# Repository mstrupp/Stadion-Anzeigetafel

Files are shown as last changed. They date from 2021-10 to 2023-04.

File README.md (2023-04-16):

# Stadion-Anzeigetafel

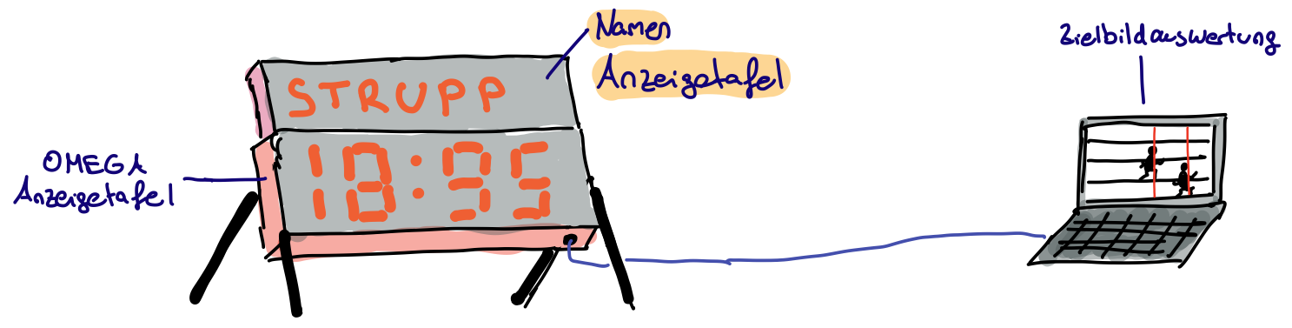
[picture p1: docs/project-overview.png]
Skizze des Projekts


## Zusammenfassung

Bei Leichtathletik Wettkämpfen erfolgt die Zeitmessung mit einer elektronischen Zeitmessanlage.
Der Startschuss startet die Stoppuhr und ein Zielbildauswerter bestimmt auf den Zielbildern die Zeiten der Läufer.

Während den Rennen wird auf einer Anzeigetafel die verstrichene Zeit dargestellt.
Außerdem können darauf nach einem Rennen die Zeiten der Läufer angezeigt werden.

In diesem Projekt wird eine Anzeigetafel entwickelt, die mit Zeitmesssystemen der Marke OMEGA kompatibel ist.
Die Anzeige kann eigenständig oder unterstützend eingesetzt werden.
Im eigenständigen Aufbau übernimmt sie alle Aufgaben der Anzeigetafel.
Im unterstützenden Modus werden Zusatzinformationen, wie der Name des Läufers, angezeigt, während eine weitere Anzeigetafel die Zeiten einblendet.

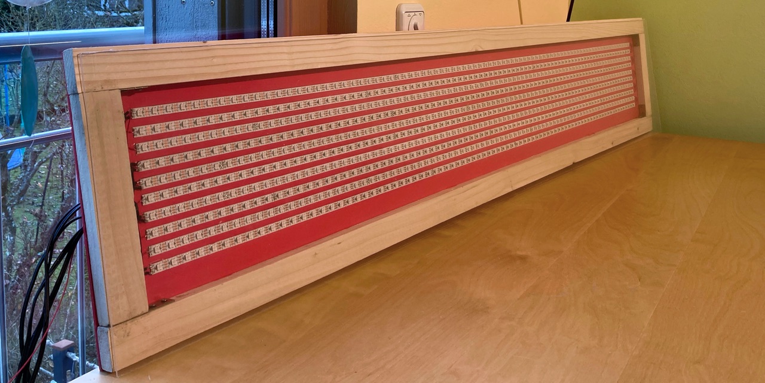
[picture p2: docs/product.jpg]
Fertiggestellte Anzeigetafel


## Technische Daten

Die Namen-Anzeigetafel ist ein LED-Display, das bis zu 12 Buchstaben in einer Zeile anzeigen kann.
Es ist aus einer Distanz von bis zu 75 m lesbar.
Der Benutzer kann zwischen verschiedenen Modi wählen, um den Namen, die Bahn oder die Platzierung anzuzeigen.
Die Helligkeit der Anzeige wird automatisch an die aktuellen Lichtverhältnisse angepasst.
Das regensichere Gehäuse schützt die Elektronik auch bei schlechtem Wetter mit der Schutzklasse IP24.

## Aufbau

### LED Anzeige

Das Display besteht aus einer LED-Matrix.
Dafür werden individuell adressierbare LED-Streifen verwendet. Die LED-Streifen haben eine Dichte von 60 LEDs pro Meter.
Der Pixel-Abstand beträgt etwa 1,7 cm.
Die Anzeige hat eine Auflösung von 83 x 10 Pixeln.
Die Maße der Anzeige betragen etwa 140 x 17 cm.
Jeder Buchstabe ist damit 6 x 10 Pixel bzw. 10 cm x 17 cm groß.

### Mikrocontroller

Die Ergebnis-Daten werden von einem STM Mikrocontroller auf einem Nucleo-32 Board empfangen und aufbereitet.
Die Daten werden von der Zielbildauswertung über die serielle RS422 Schnittstelle bereitgestellt.
Der Mikrocontroller berechnet unter den gegeben Benutzer-Einstellungen die Steuerungssignale für das Display.

### Schnittstellen

Für den Daten-Empfang wird der Data-Out Anschluss der OMEGA-Anzeigetafel verwendet.
Die Verbindung erfolgt über ein Datenkabel mit einem siebenpoligem Tuchel-Anschluss.
Zum Programmieren des Mikrocontrollers ist außerdem ein USB Anschluss am Gehäuse angebracht.

### Automatische Helligkeitsregulierung

Die Helligkeit der Anzeige wird automatisch an die aktuellen Lichtverhältnisse angepasst.
Zur Ermittlung der Umgebungshelligkeit wird ein Fotowiderstand eingesetzt.
Bei starker Sonneneinstrahlung wird zur verbesserten Lesbarkeit die Helligkeit des Displays erhöht.
Bei Dunkelheit wird die Helligkeit verringert.

### Betriebsmodi

Die Anzeigetafel verfügt über verschiedene Betriebsarten.
Es kann entweder der Name oder die Startnummer und die Bahn angezeigt werden.
Über Schalter kann der Bediener auswählen, was angezeigt wird. Ein weiterer Schalter aktiviert das Scrollen von langen Namen, die nicht mit zehn Zeichen dargestellt werden können.
Über ein Potentiometer kann die Helligkeit manuell justiert werden.
Das Ein- und Ausschalten des Geräts ist ebenfalls über einen Schalter möglich.

### Spannungsversorgung

Sowohl der Arduino als auch die LED Streifen benötigen eine elektrische Spannung von 5 V. Diese wird über ein externes Netzteil bereitgestellt.

### Gehäuse

Das Gehäuse besteht aus PVC und bietet damit Schutz vor Regen in der Sicherheitsklasse IP24.
Die Vorderseite besteht aus einer dunklen Plexiglas Scheibe, um die gute Lesbarkeit der Anzeige zu ermöglichen.

## Schaltplan

Zum Einstellen des Modus werden Kippschalter, Potentiometer und Drehschalter verwendet.
Außerdem ermitteln Sensoren die Helligkeit und Temperatur.
Die Komponenten werden auf einer Platine mit dem Mikrocontroller und miteinander verbunden.

[Schaltplan](PCB-Eagle/Anzeigetafel-Schaltplan.pdf)

[PCB](PCB-Eagle/Anzeigetafel-PCB.pdf)

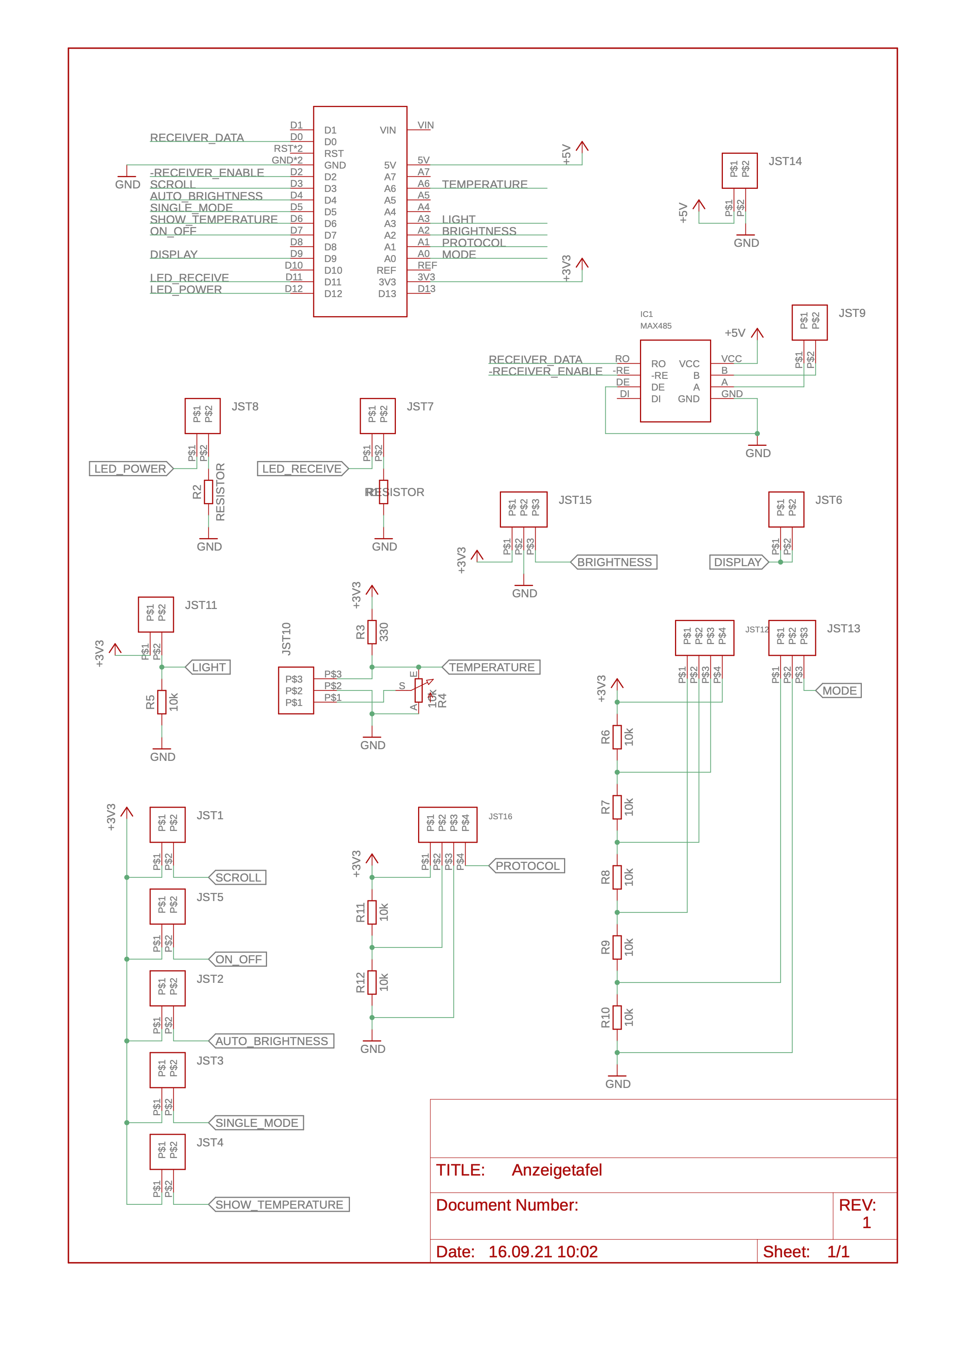
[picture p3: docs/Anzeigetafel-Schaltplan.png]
Schaltplan


## Steuerung der Anzeige

Die Anzeige besteht aus einer LED-Matrix mit 840 RGB LEDs. Die LEDs sind in Reihen auf LED-Streifen angebracht. Jede einzelne RGB LED besteht aus drei kleinen LEDs in den Farben Rot, Grün und Blau. Durch Kombination der einzelnen Farb-LEDs kann ein breites Farbspektrum erzeugt werden.

### WS2812B RGB LED Streifen

Auf den LED-Streifen sind WS2812B ICs angebracht, die die einzelnen LEDs steuern. Alle ICs sind in Reihe geschaltet. Vom Mikrocontroller werden nacheinander die Farbcodes für die einzelnen LEDs gesendet.

Der erste Chip empfängt das Steuersignal und verarbeitet den ersten Farbcode. Daraufhin enterfernt der IC den ersten Farbcode aus dem Steuersignal und gibt das resultierene Signal an die folgenden Chips weiter.
Die nächsten ICs wiederholen das Vorgehen. Somit wird das Steuersignal von Chip zu Chip kürzer, bis es den letzten Chip erreicht. Am Ende des Steuersignals wird ein Reset-Signal gesendet [3].

Ablauf Steuerung WS2812B ICs

Abbildung: Ablauf der WS2812B Steuerung

### Benötigte Signale

Jeder Farbcode besteht aus 24 Bit beziehungsweise 3 Byte. In jedem Byte ist die Intensität einer Farbe enthalten. Im ersten Byte ist der Grünwert, im zweiten der Rotwert und im dritten Byte der Blauwert kodiert. Daraus entstehen drei Werte, die von 0 bis 256 reichen. Diese ergeben den RGB-Wert der LED [3].

Aufbau eines Farbcodes

Abbildung: Aufbau eines Farbcodes

Die 24 Bit je Farbcode werden elektrisch über ein Datenkabel an die Chips gesendet. Die Spannung auf dem Kabel wird entweder auf "high" oder "low" gesetzt (3,3 V oder 0 V). Je nachdem, wie lange das Signal im Zustand "high" und "low" verbringt, wird es als "0" oder "1" interpretiert. Die genauen Zeitverhältnisse sind in folgender Abbildung dargestellt [3].

Timing der Signale

Abbildung: Timing der Signale

Die Periode für das Senden einer 0/1-Signals beträgt 1,25 µs. Die high/low-Signale haben eine Toleranz von ±150 ns.

Nachdem die Farbcodes aller LEDs gesendet wurden, folgt ein Reset-Signal. Dazu wird die Datenleitung für mindestens 50 µs auf "low" gebracht [3].

### Erzeugung der Signale

Der Mikrocontroller verfügt über verschiedene Timer. Ein Timer mit PWM (Pulsweitenmodulation) Unterstützung wird für die Erzeugung der Steuersignale verwendet [2].

Die PWM-Periode muss wie gefordert auf 1,25 µs, was einer Frequenz von 800 kHz entspricht, gestellt werden.
Der Timer arbeitet mit einer Frequenz von 64 MHz.
Wenn der Timer innerhalb von einer Periode von 0 bis 79 zählt und dann zurückgesetzt wird, kann die erforderliche Frequenz erreicht werden.

Durch Einstellen des Tastgrades / Duty Cycles kann das Verhältnis von "high" und "low" innerhalb einer Periode geändert werden.

Bei einem Tastgrad von a = 0,32 wird ein "0"-Signal und bei einem Tastgrad von a = 0,64 ein "1"-Signal erzeugt.

#### Direct Memory Access

Der Tastgrad muss also ständig geändert werden.
Wenn die CPU dafür benutzt wird, kann nicht sichergestellt werden, dass das Timing eingehalten wird.
Es würde alle 1,25 µs ein gespeicherter Tastgrad-Wert geladen und ins Timer Register geschrieben werden.
Außerdem ist die CPU somit während dem Senden eines Signals durchgehend ausgelastet und kann nicht auf andere Signale reagieren.

Deshalb wird die DMA (Direct Memory Access) Funktion des Mikrocontrollers eingesetzt.
Diese schafft eine direkte Verbindung zwischen den Speicheradressen der Tastgrade und dem PWM Registers des Timers.
Die CPU startet zu Beginn die DMA-Verbindung.
Dann wird automatisch nach jeder Timer Periode der neue Tastgrad eingestellt [2].

Skizze Direct Memory Access

Abbildung: Skizze Direct Memory Access

### Double Buffering

Insgesamt besitzt die Anzeigetafel 840 Pixel.
Wie beschrieben bekommt jeder Pixel ein 24 Bit langes Datensignal.
Für jedes Bit muss der Tastgrad angepasst werden.
Die Tastgrade werden in einem Array gespeichert und dann per DMA an den Timer gegeben.
In dem Array wird jeder Wert als `uint8_t` gespeichert und belegt somit 1 Byte des RAMs.

Das bedeutet, dass das Array eine Speichergröße von 840 * 24 Byte = 20,16 Kilobyte beansprucht.
Das übersteigt die Größe des RAMs des Mikrocontrollers (8 Kilobyte) bei weitem.

Double Buffering wird eingesetzt, um den Speicherbedarf stark zu verringern [4].

Statt ein Array mit allen Tastgraden anzulegen, wird lediglich ein Array mit 48 Einträgen erzeugt.
Dieses bietet Platz für die Tastgrade von genau zwei LEDs.

Der DMA wird im "Circle Mode" konfiguriert.
In diesem Modus sendet er das angegebene Array and die ausgewählte Peripherie und startet dann von vorne.

Dieses Verhalten wird ausgenutzt, um alle LEDs mit dem 48 Byte großen Array anzusteuern.
Zuerst werden die Tastgrade für LED 1 und LED 2 in das Array geladen und der DMA gestartet.
Sobald das Signal für LED 1 generiert wurde, beginnt der DMA, die Tastgrade für LED 2 weiterzugeben.
Währenddessen werden die Tastgrade für LED 1 mit den Tastgraden für LED 3 überschrieben.
Wenn LED 2 gesendet wurde, beginnt der DMA von vorne.
In der ersten Hälfte des Arrays stehen nun die Tastgrade für LED 3 und dadurch wird das dazugehörige Signal generiert.
Das Vorgehen wird wiederholt, bis die Signale für alle LEDs gesendet wurden [4].
Zuletzt wird der Tastgrad auf "0" gesetzt, um das Reset-Signal zu erzeugen.

Ablauf des DMA mit Double Buffering

Abbildung: Ablauf des DMA mit Double Buffering

Der DMA löst Interrupts aus, über die das Tastgrade-Array dann angepasst werden kann.
Wenn die erste Hälfte des Arrays gesendet wurde, wird die Funktion `HAL_TIM_PWM_PulseFinishedHalfCpltCallback` aufgerufen.
Wenn die zweite Hälfte des Arrays gesendet wurde, wird `HAL_TIM_PWM_PulseFinishedCallback` aufgerufen [1].
In diesen Funktionen kann dann das Array mit den neuen Tastgraden befüllt werden.

Auslösen der Interrupts/Callbacks

Abbildung: Auslösen der Interrupts/Callbacks

Die CPU wird beim DMA mit Double Buffering alle 30 µs verwendet.
Damit wird sie 24 Mal weniger belastet als beim Vorgehen ohne DMA.

Das Tastgrade-Array beinhaltet 48 32-Bit Zahlen.
Die Speichergröße beträgt damit 192 Byte.
Dabei spielt es keine Rolle, wie viele LEDs angesteuert werden.
Somit wird im Vergleich zum DMA ohne Double Buffering nur ein Hundertstel des Speicherplatzes verwendet.

## Programm-Repräsentation der LED-Matrix

Um die Verkabelung zu vereinfachen, sind die LEDs im Zickzack auf der Anzeigetafel aufgebrahcht.
In der ersten Zeile läuft das Datensignal daher von links nach rechts, in der zweiten von rechts nach links und so weiter.
Jeder LED wird ein Index, beginnend bei 0, zugeordnet.

Im Programm werden die Farbwerte aller LEDs in einem Array gespeichert.
Die Indizierung unterscheidet sich dadurch in jeder zweiten Zeile, wie in der folgenden Abbildung dargestellt.

LED-Matrix und Array Indizierung

Abbildung LED-Matrix und Array Indizierung

Wie zu sehen ist, unterscheiden sich die Indizierung der realen LED-Matrix und die des Arrays in jeder zweiten Zeile.
Um die Buchstaben und Zahlen trotzdem lesbar anzuzeigen, muss der Programmcode entsprechend angepasst werden.

### Programm eines Buchstaben, einer Zahl oder anderen Zeichens

Jedes Zeichen, das angezeigt werden soll, besteht aus einer Matrix.
Diese gibt an, welche LEDs für dieses Zeichen an- und ausgeschaltet werden sollen.

```C
const Character char0x41 = { // A
        .width = 6,
        .height = 10,
        .matrix = {
                0, 0, 1, 1, 0, 0,
                0, 1, 0, 0, 1, 0,
                1, 0, 0, 0, 0, 1,
                1, 0, 0, 0, 0, 1,
                1, 0, 0, 0, 0, 1,
                1, 1, 1, 1, 1, 1,
                1, 0, 0, 0, 0, 1,
                1, 0, 0, 0, 0, 1,
                1, 0, 0, 0, 0, 1,
                1, 0, 0, 0, 0, 1
        }
};
```

Listing: Code für den Buchstaben A

### Programm zum Füllen der LED-Matrix

Folgender Code wird dann zum Füllen des Arrays verwendet.

```C
// Set a character at the current cursor position in the given color.
void LEDMatrixSetCharacter(LEDMatrix* ledMatrix, const Character* character, Color color) {
    int currentCursorPos;;
    // Iterate over all character cells
    for (int line = 0; line < character->height; ++line) {
        currentCursorPos = ledMatrix->cursorPos;
        for (int col = 0; col < character->width; ++col) {
            // Check if the column is inside the matrix
            if (currentCursorPos >= 0 && currentCursorPos < ledMatrix->numCols) {
                // Even line: LEDs from left to right
                if (line % 2 == 0) {
                    ledMatrix->leds[line * ledMatrix->numCols + col + ledMatrix->cursorPos].color =
                            character->matrix[line * character->width + col] ? color : off;
                // Uneven line: LEDs from right to left
                } else {
                    ledMatrix->leds[line * ledMatrix->numCols + (ledMatrix->numCols - 1 - col) - ledMatrix->cursorPos].color =
                            character->matrix[line * character->width + col] ? color : off;
                }
            }
            currentCursorPos += 1;
        }
    }
}
```

Listing: Code zum Hinzufügen eines Buchstaben zur Matrix

An die Funktion werden die LED-Matrix, das neue Zeichen und die Farbe übergeben.
Es wird über jede Zelle der Buchstaben-Matrix iteriert.
Wenn die berechnete Zelle innerhalb der LED-Matrix liegt, wird die zugehörige LED angeschaltet.
Mithilfe von `if (line $ 2 == 0)` wird getestet, ob die Zeile gerade oder ungerade ist.
Wie zuvor beschrieben wird dementsprechend die Beschreibe-Richtung der LED-Matrix angepasst.
Beim Setzen der LED wird dann außerdem die Farbe dieser LED festgelegt.

### Animationen

Unter Benutzung eines weiteren Timers ist es möglich, Animationen auf der Anzeigetafel abzuspielen.
Der Quellcode dafür befindet sich im Ordner `animations`.
Die Animation `SwipeClearAnimation` lässt zum Beispiel einen Streifen von links nach rechts über die Anzeige wischen, der dabei all Zeichen löscht.

Bei Animationen ist zu beachten, dass die Aktualisierungsrate der Anzeige von der Anzahl der LEDs abhängt.
Die Signallänge jedes Bits 1,25 µs.
Für jede LED werden 24 Bit gesendet.
Nach dem Senden aller LED-Signale folgt ein Reset-Puls mit einer Dauer von 50 µs.
Die benötigte Zeit zum Senden eines gesamten Bildes ergibt sich damit zu

`T = n * 24 * 1,25 µs + 50 µs`,
wobei `n` die Anzahl der LEDs ist.

Für die im Projekt verwendeten n = 830 LEDs ergibt sich damit eine Sendezeit von 24,95 ms.
Damit liegt die theoretisch mögliche Aktualisierungsrate bei etwa 4 Bildern pro Sekunde.

## Empfang der Daten

Die Anzeige-Befehle werden über die RS422 Schnittstelle bereitgestellt.
Der MAX485 IC leitet die Daten als für den Mikrocontroller lesbares Signal weiter.
Es gibt verschiedene Protokolle, in denen die Informationen empfangen werden können.
Das Projekt unterstützt das Gemini sowie das Rollertime Protokoll.
Die Dekodierunds-Funktionen sind in den Quelldateien im Ordner `protocols` implementiert.

In den Dekodierungs-Funktionen werden die empfangenen Daten anylisert und geprüft, um welchen Datentyp es sich handelt.
Im Gemini Protokoll kann zum Beispiel enthalten sein:

- Aktuelle Zeit
- Name eines Athleten
- Ergebnis eines Athleten
- Startnummer eines Athleten
- Bahn eines Athleten
- Platzierung eines Athleten
- Clear-Kommando

Je nach empfangenem Signal wird dann entschieden, was auf der Anzeige dargestellt werden soll und die LED-Signale generiert und versendet.

## Gamma Korrektur

```text
corrected = ((value / 255) ^ gamma) * 255
```

Als Gamma Wert wird 2,5 benutzt.

## Referenzen

[1] STMicroelectronics, Description of STM32G0 HAL and low-layer drivers - User manual. 10-2020.

[2] STMicroelectronics, STM32G0x1 advanced Arm®-based 32-bit MCUs - Reference manual. 11-2020.

[3] Worldsemi, WS2812B Datenblatt. 2021.

[4] M. Tilen, “Tutorial: Control WS2812B leds with STM32,” 2018-06-03. <https://stm32f4-discovery.net/2018/06/tutorial-control-ws2812b-leds-stm32/>

[5] Maxim Integrated, MAX485 Datenblatt. 9-2014.

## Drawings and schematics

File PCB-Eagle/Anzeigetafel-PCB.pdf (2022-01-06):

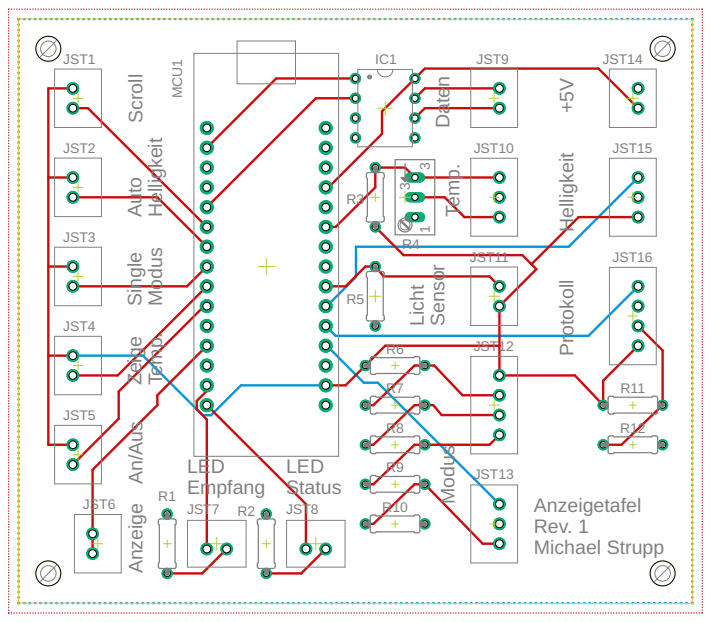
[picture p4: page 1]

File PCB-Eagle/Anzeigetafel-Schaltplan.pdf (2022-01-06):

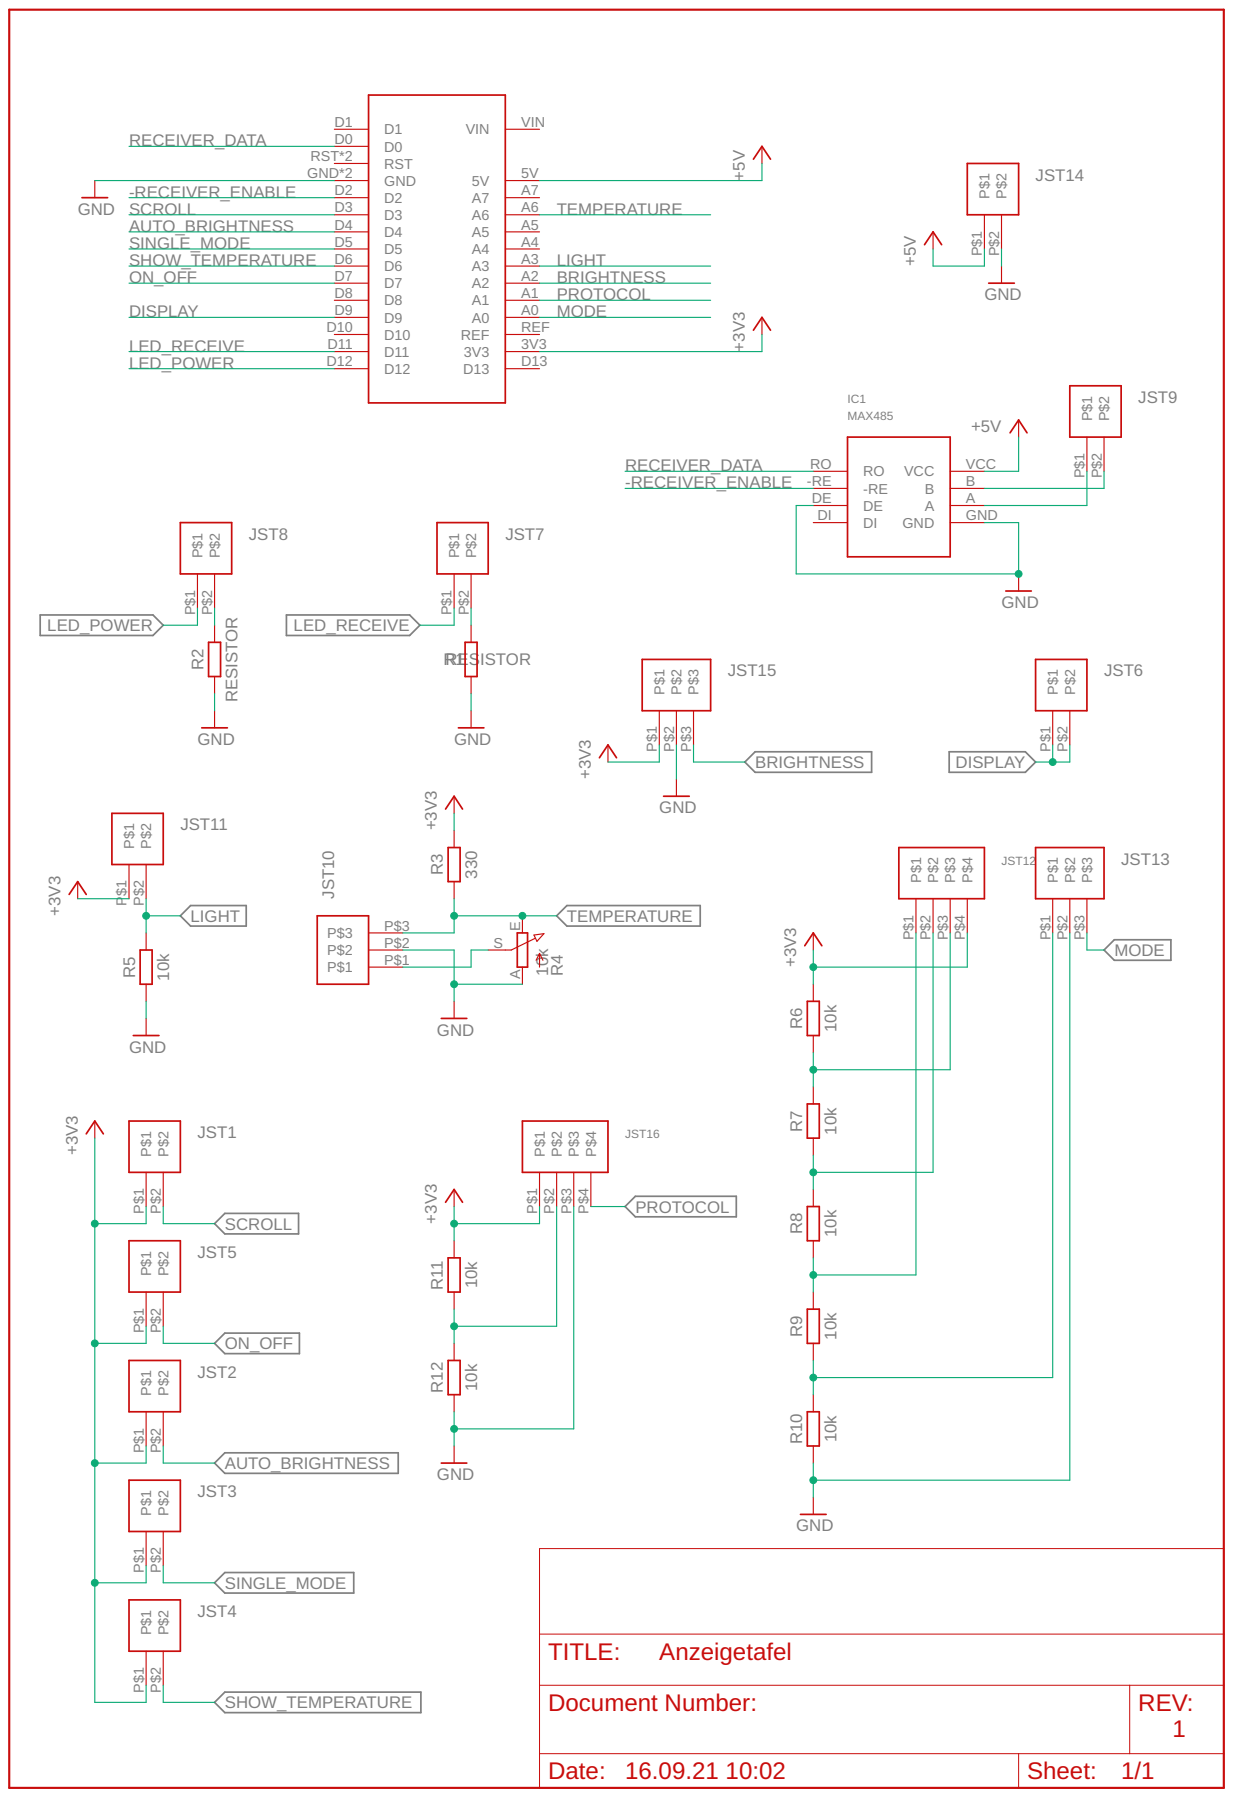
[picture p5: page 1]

Document Number: | REV: 1

Date: 16.09.21 10:02 | Sheet: 1/1

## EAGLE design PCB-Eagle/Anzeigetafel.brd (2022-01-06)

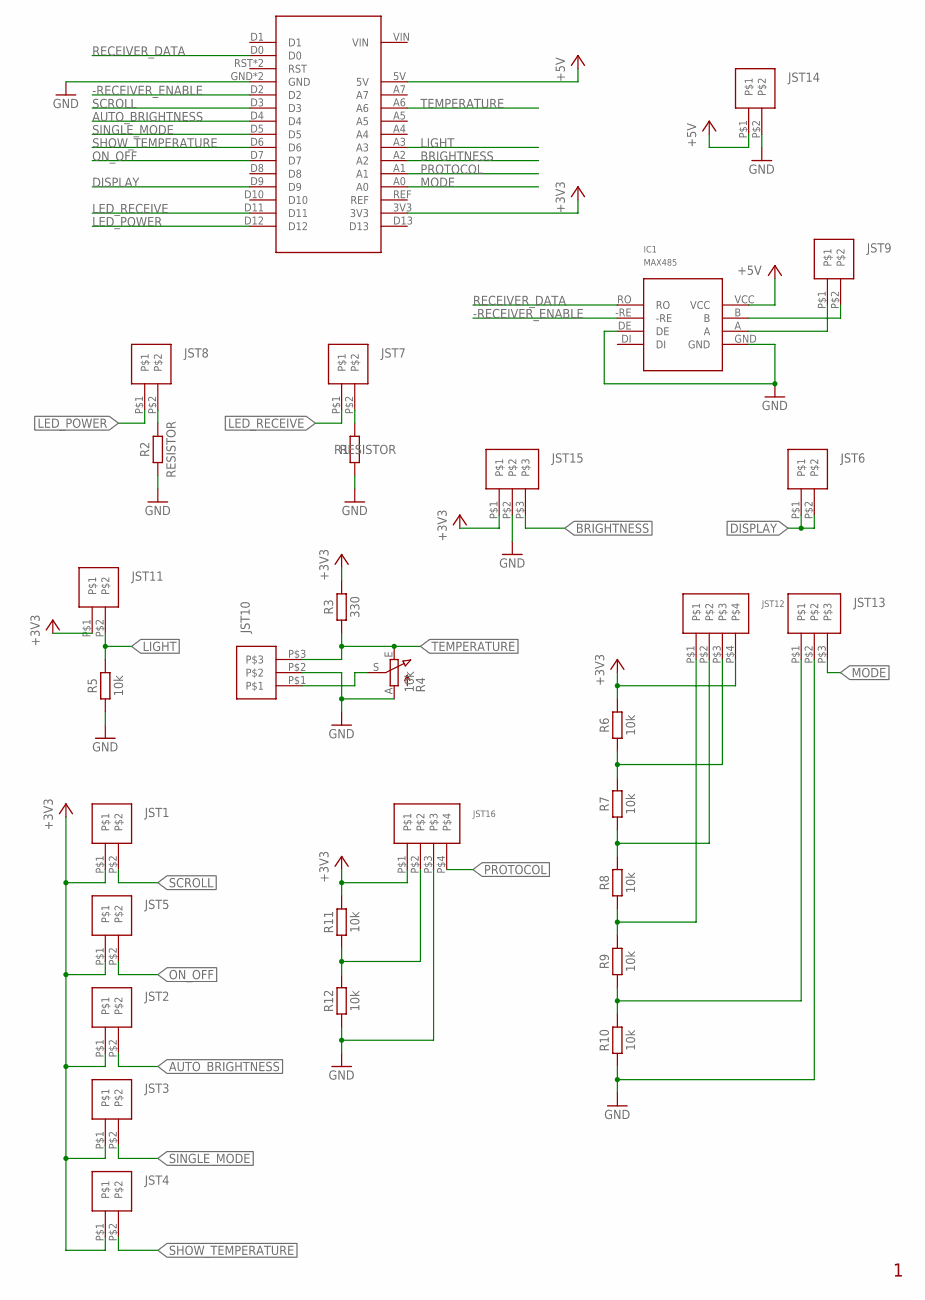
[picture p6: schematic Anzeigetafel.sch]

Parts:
IC1: MAX485
JST1, JST2, JST3, JST4, JST5, JST6, JST7, JST8, JST9, JST11, JST14: JST-2
JST10, JST13, JST15: JST-3
JST12, JST16: JST-4
MCU1: NUCLEO-32G0
R1, R2: RESISTOR; 0207/7
R3: 330; 0207/7
R4: 10k; S64W
R5, R6, R7, R8, R9, R10, R11, R12: 10k; 0207/7

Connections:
+3V3: JST1.P$1, JST2.P$1, JST3.P$1, JST4.P$1, JST5.P$1, JST11.P$1, JST12.P$4, JST15.P$1, JST16.P$1, MCU1.3V3, R3.2, R6.2, R11.2
+5V: IC1.VCC, JST14.P$1, MCU1.5V
-RECEIVER_ENABLE: IC1.-RE, MCU1.D2
AUTO_BRIGHTNESS: JST2.P$2, MCU1.D4
BRIGHTNESS: JST15.P$3, MCU1.A2
DISPLAY: JST6.P$1, JST6.P$2, MCU1.D9
GND: IC1.DE, IC1.GND, JST10.P$2, JST13.P$2, JST14.P$2, JST15.P$2, JST16.P$3, MCU1.GND, MCU1.GND1 (GND), R1.1, R2.1, R4.A, R5.1, R10.1, R12.1
LED_POWER: JST8.P$1, MCU1.D12
LED_RECEIVE: JST7.P$1, MCU1.D11
LIGHT: JST11.P$2, MCU1.A3, R5.2
MODE: JST13.P$3, MCU1.A0
unnamed: JST8.P$2, R2.2
unnamed: IC1.A, JST9.P$1
unnamed: JST7.P$2, R1.2
unnamed: JST10.P$1, R4.S
unnamed: IC1.B, JST9.P$2
unnamed: JST12.P$3, R6.1, R7.2
unnamed: JST12.P$2, R7.1, R8.2
unnamed: JST12.P$1, R8.1, R9.2
unnamed: JST13.P$1, R9.1, R10.2
unnamed: JST16.P$2, R11.1, R12.2
ON_OFF: JST5.P$2, MCU1.D7
PROTOCOL: JST16.P$4, MCU1.A1
RECEIVER_DATA: IC1.RO, MCU1.D0
SCROLL: JST1.P$2, MCU1.D3
SHOW_TEMPERATURE: JST4.P$2, MCU1.D6
SINGLE_MODE: JST3.P$2, MCU1.D5
TEMPERATURE: JST10.P$3, MCU1.A6, R3.1, R4.E

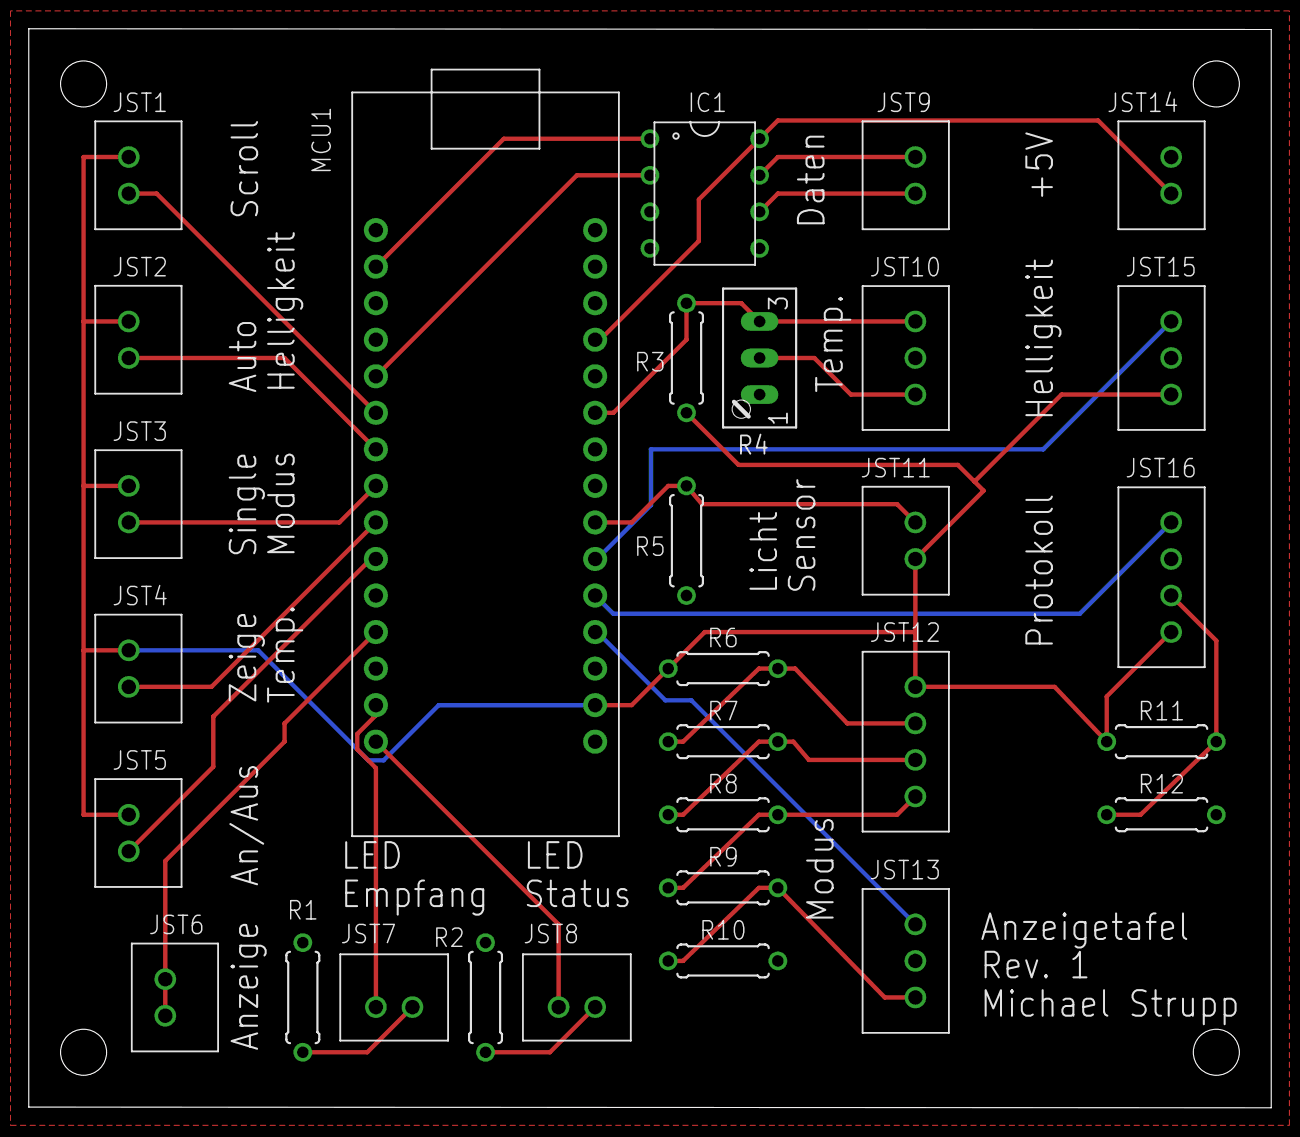
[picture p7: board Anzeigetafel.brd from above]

Board: 2 copper layers, 86.4 x 75.0 mm, 30 parts (0 on the bottom side), 28 nets.

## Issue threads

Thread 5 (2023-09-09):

Stuck in title scroll

mstrupp, 2023-09-09:
The scoreboard gets stuck displaying the competition title. Not even clear works.

Temporary workaround seems to be switching on the main and second scoreboard at the same time.

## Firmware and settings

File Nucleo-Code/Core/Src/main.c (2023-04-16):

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
/* Includes ------------------------------------------------------------------*/
#include "main.h"

/* USER CODE BEGIN Includes */
#include "LED.h"
#include "LEDMatrix.h"
#include "animations/ScrollAnimation.h"
#include "animations/SwipeClearAnimation.h"
#include "RS485Receiver.h"
#include "Scoreboard.h"
#include "TemperatureSensor.h"
/* USER CODE END Includes */

/* USER CODE BEGIN PD */
#define numLEDs 830
#define numCols 83
/* USER CODE END PD */

ADC_HandleTypeDef hadc1;

TIM_HandleTypeDef htim1;
TIM_HandleTypeDef htim2;
DMA_HandleTypeDef hdma_tim1_ch1;

UART_HandleTypeDef huart1;

/* USER CODE BEGIN PV */
LEDMatrix ledMatrix;
RS485Receiver receiver;
ScrollAnimation scrollAnimation;
SwipeClearAnimation swipeClearAnimation;
TemperatureSensor temperatureSensor;

Scoreboard scoreboard;
/* USER CODE END PV */

void SystemClock_Config(void);
static void MX_GPIO_Init(void);
static void MX_DMA_Init(void);
static void MX_TIM1_Init(void);
static void MX_TIM2_Init(void);
static void MX_USART1_UART_Init(void);
static void MX_ADC1_Init(void);
/**
  * @brief  The application entry point.
  * @retval int
  */
int main(void)
{
  /* MCU Configuration--------------------------------------------------------*/

  /* Reset of all peripherals, Initializes the Flash interface and the Systick. */
  HAL_Init();

  /* USER CODE BEGIN Init */
  LEDMatrixInit(&ledMatrix, numLEDs, numCols, &htim1, TIM_CHANNEL_1);
  ScrollAnimationInit(&scrollAnimation, &ledMatrix, &htim2, 80);
  SwipeClearAnimationInit(&swipeClearAnimation, &ledMatrix, &htim2, 2000, debug);
  RS485ReceiverInit(&receiver, &huart1);
  TemperatureSensorInit(&temperatureSensor, &hadc1);
  ScoreboardInit(&scoreboard, &ledMatrix, &receiver, &swipeClearAnimation, &scrollAnimation, &temperatureSensor);
  /* USER CODE END Init */

  /* Configure the system clock */
  SystemClock_Config();

  /* Initialize all configured peripherals */
  MX_GPIO_Init();
  MX_DMA_Init();
  MX_TIM1_Init();
  MX_TIM2_Init();
  MX_USART1_UART_Init();
  MX_ADC1_Init();
  /* USER CODE BEGIN 2 */
  ScoreboardStart(&scoreboard);
  /* USER CODE END 2 */

  /* Infinite loop */
  /* USER CODE BEGIN WHILE */
  while (1) {

    /* USER CODE END WHILE */

    /* USER CODE BEGIN 3 */
  }
  /* USER CODE END 3 */
}

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
/* USER CODE BEGIN 4 */

void HAL_TIM_PWM_PulseFinishedHalfCpltCallback(TIM_HandleTypeDef * htim) {
	if (htim == &htim1) {
		// Fill the DMA buffer with next duty cycles
		LEDMatrixBufferHalfSentCallback(&ledMatrix);
	}
}

void HAL_TIM_PWM_PulseFinishedCallback(TIM_HandleTypeDef * htim) {
	if (htim == &htim1) {
		// Fill the DMA buffer with next duty cycles
		LEDMatrixBufferSentCallback(&ledMatrix);
	}
}

void HAL_TIM_PeriodElapsedCallback(TIM_HandleTypeDef * htim) {
	if (htim == &htim2) {
		ScrollAnimationCallback(&scrollAnimation);
		SwipeClearAnimationCallback(&swipeClearAnimation);
	}
}

void HAL_UART_RxCpltCallback(UART_HandleTypeDef* huart) {
	ScoreboardMain(&scoreboard);
}

/* USER CODE END 4 */
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


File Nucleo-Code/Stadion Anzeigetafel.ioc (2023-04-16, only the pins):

Mcu.UserName=STM32G031K8Tx
PA13.GPIO_Label=T_JTMS
PA13.Signal=SYS_SWDIO
PA14-BOOT0.GPIO_Label=T_JTCK
PA14-BOOT0.Signal=SYS_SWCLK
PA15.GPIO_Label=NOT_RECEIVER_ENABLE
PA15.Signal=GPIO_Output
PA2.GPIO_Label=T_VCP_TX
PA2.Signal=USART2_TX
PA3.GPIO_Label=T_VCP_RX
PA3.Signal=USART2_RX
PA6.Signal=ADC1_IN6
PA8.Signal=S_TIM1_CH1
PB6.Signal=USART1_TX
PB7.Signal=USART1_RX
PC6.GPIO_Label=LD3 [Green]
PC6.Signal=GPIO_Output

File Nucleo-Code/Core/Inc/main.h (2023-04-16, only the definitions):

#define T_NRST_Pin GPIO_PIN_2
#define T_NRST_GPIO_Port GPIOF
#define T_VCP_TX_Pin GPIO_PIN_2
#define T_VCP_TX_GPIO_Port GPIOA
#define T_VCP_RX_Pin GPIO_PIN_3
#define T_VCP_RX_GPIO_Port GPIOA
#define LD3_Pin GPIO_PIN_6
#define LD3_GPIO_Port GPIOC
#define T_JTMS_Pin GPIO_PIN_13
#define T_JTMS_GPIO_Port GPIOA
#define T_JTCK_Pin GPIO_PIN_14
#define T_JTCK_GPIO_Port GPIOA
#define NOT_RECEIVER_ENABLE_Pin GPIO_PIN_15
#define NOT_RECEIVER_ENABLE_GPIO_Port GPIOA

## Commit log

2021-09-24 Added led control functions - LED stores the information about single LEDs - LEDMatrix stores the whole array of LEDs, LED pattern logic and PWM generation functions.
2021-09-24 Added code for PWM generation - Send buffer using DMA callbacks - Including example code
2021-09-24 Fixed LED initialization - Call the init function
    [LEDMatrix.c]
2021-09-24 Increased maximum number of LEDs - From uint8_t (256) to uint32_t (more than enough)
2021-09-27 Started led control documentation
2021-09-30 Small improvements - Option to change duty cycles to use other ICs than WS2812B - Added color amber - Improved example code, now possible to use more LEDs
2021-09-30 Added matrix manipulation functions - Added font.h where all characters will be stored - Added test character letterA - Added matrix clear function - Added set matrix character test function - Introd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
2021-10-01 Added function to set a string to the LED matrix - Added LEDMatrixAddText function - Added getCharacter function that matches a char to a Character
2021-10-01 Added aligntment - Set the alignment with LEDMatrixSetAlignment to left, center, right or append
2021-10-01 Avoid pixel overflows in matrix to the left and to the right - Adds support for negative cursor positions
    [LEDMatrix.c]
2021-10-01 Added Animation capability - Added SwipeClearAnimation as example - Moved Character from font to own file - Moved font.h and font.c in fonts folder - Made LEDMatrixSetCharacter public - Set up Timer 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
2021-10-07 Added functions to read and process RS485 control messages from the photofinish PC
    - Enabled the microcontroller uart
    - RS485Receiver handles the uart and checks for messages
    - Message is a struct that can save all relevant information of a received message
    - geminiGenerateMessage and rollertimeGenerateMessage convert the received strings to Message structs according to the corresponding protocols
    - Scoreboard is the top level function that will control the complete system.
    ScoreboardMain is called when a new serial message is received. The new matrix output will then be determined and sent to the LEDs.
    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
2021-10-22 Minor improvements
    - Added debug color (very dim color that does not hurt your eyes while debugging)
    - Bugfix in gemini receive protocol
    [LED.c]
2021-10-22 Receive RS422 commands and various improvements
    - Process and display basic commands from photofinish PC
    - Added complete alphabet and numbers to font.
    - LEDMatrix now checks if a code is currently being sent. Don't accept new send requests while sending.
    - Made SwipeClearAnimation compatible with 10 pixel high led matrix.
    - Increased matrix send timer interrupt priority
2022-01-06 Added PCB design files
    [Anzeigetafel.brd, Anzeigetafel.sch]
2022-01-06 Improved documentation
    - Added circuit diagram
2022-01-06 Added circuit diagram image in documentation
2022-09-08 Added Temperature Sensor
2023-04-15 Optimization and recalculation
    - Reduce reset time to 72 us
    - Corrected max FPS calculation
    [LEDMatrix.c]
2023-04-15 Scroll Animation Bugfix
    - Dynamically allocate array of leds
    - Fixed display glitch when scroll animation repeats
    [LEDMatrix.c, ScrollAnimation.c, main.c]
2023-04-16 Various Improvements
    - Added show requests: Show later if matrix is currently sending
    - Fixed Scroll Animation
    - Small fix in swipe clear animation
    - Preparations for WHS 2023
    [LEDMatrix.c, ScrollAnimation.c, SwipeClearAnimation.c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]

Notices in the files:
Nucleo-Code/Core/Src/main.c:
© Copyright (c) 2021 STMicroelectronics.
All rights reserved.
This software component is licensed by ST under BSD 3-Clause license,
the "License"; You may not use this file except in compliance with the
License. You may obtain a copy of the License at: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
